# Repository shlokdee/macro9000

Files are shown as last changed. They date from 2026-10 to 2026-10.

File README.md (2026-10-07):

# macro9000
a compact hand wired macropad!
macro9000 is a 9 key rp2040 and qmk based customisable macropad! it can be made without needing to manufacture a pcb! 
it also modularly attaches via trrs cable and uart, with splitkey9000, my hand wired split keyboard... (wip)

### inspiration
every macropad i see has a pcb attached to it. i dont see the need for it to be honest. so i decided to make my own hand wired macropad.

### features:
* 9 customisable keys (with a webtool called via)
* qmk firmware
* fully hand wired, no pcb
* a clean look, with the keys spanning the entirety of the surface

### bom:

|component |use |qty |price |link ||
|---|---|---|---|---|---|
|RP2040-Zero |main microcontroller running qmk |1 |269 |https://robu.in/product/rp2040-zero-for-raspberry-pi-microcontroller-with-soldering/ | |
|1n4148 diode|reduce ghosting |9 |30 |https://robu.in/product/1n4148-onsemi-100v-1v10ma-4ns-200ma-do-35-switching-diodes-rohs/| |
|MX Switches |well, switches |9 (pack of 10) |~250 |TBD | |
|Keycaps |3d Printed keycaps |9 |~100 |probably robu service | |
|Wire |wiring lmao (the wire ive chosen is soo good... tins so easily)|2m (to be safe)|30 |https://robu.in/product/24awg-silicone-braided-wire-red/ | |
|casing |3d printed casing |1 |~300 |probably robu service | |
|shipping |cart values gonna be low so shipping needed lol | |~200 total| | |
|total | | |~1150 | | |
| | | |12 usd | | |
| | | | | | |

### 3d printing
the enclosure and the keycaps are 3d printed. files can be found inside the [3d files](3d_files) folder. I have attached a [3d print arranged file](3d_files/3dpassem.step), you can upload that to a slicer and print!

### schematic and wiring
this is the main schematic to use while wiring..
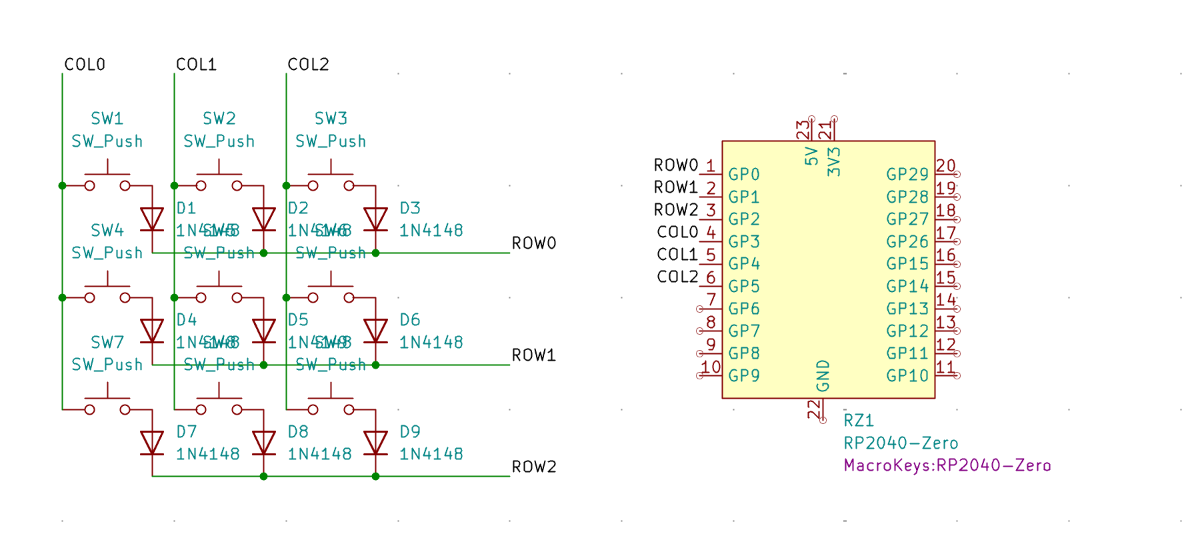
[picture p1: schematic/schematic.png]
schematic


switches should be wired after fitting into the sockets like:
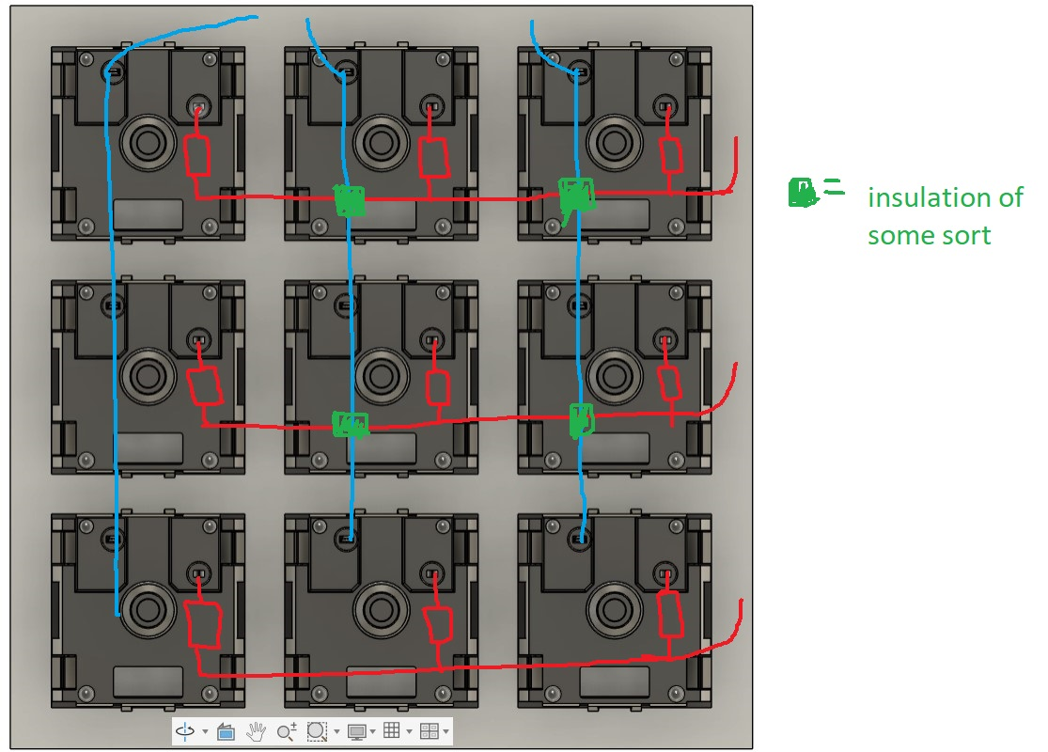
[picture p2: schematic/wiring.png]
wiring


### how to build
* 3d print the case, socket and 9 keycaps. you can use this [file](3d_files/3dpassem.step), directly upload it to the slicer, and print. high quality (0.1mm) is preffered.
* push the mx keys into the slots on the socket. its square, so doesnt matter which way. but for easy wiring, place all the 2 pin sides on the same side (as shown in the wiring diagram)
* solder the diodes, and the wires acc to the wiring diagram, make sure that the leg opposite to the black stripe is connected to the switch leg.
* mount the rp2040 zero in the box, and make the connections acc to the schematic
* mount the trrs female in the box and make its connections too (wip)
* place the socket over the box
* flash the firmware and youre good to go!

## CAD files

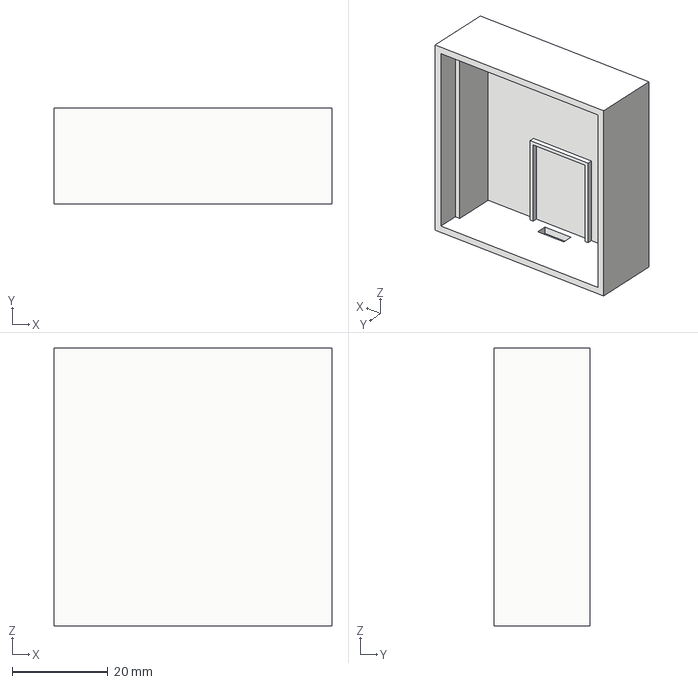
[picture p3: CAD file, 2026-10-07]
3d_files/case.step
58.2 x 20.0 x 58.2 mm

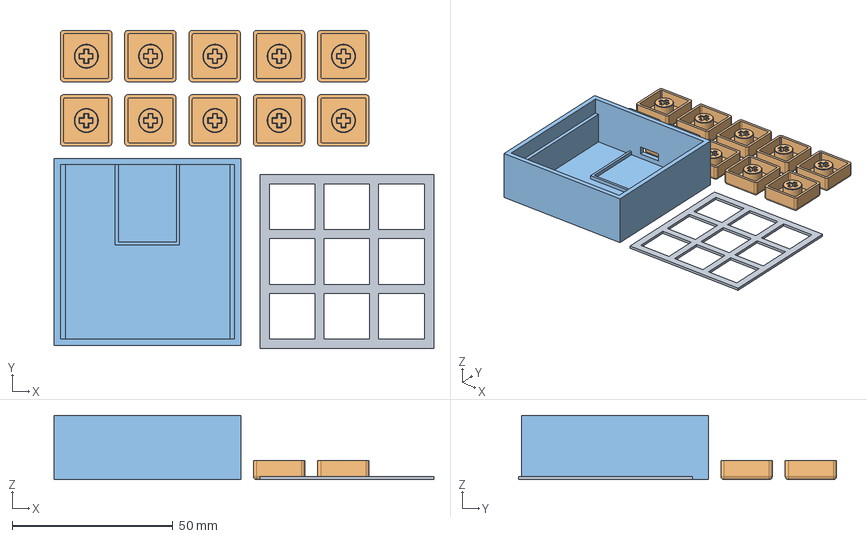
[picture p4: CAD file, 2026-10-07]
3d_files/3dpassem.step
118.2 x 99.0 x 20.0 mm

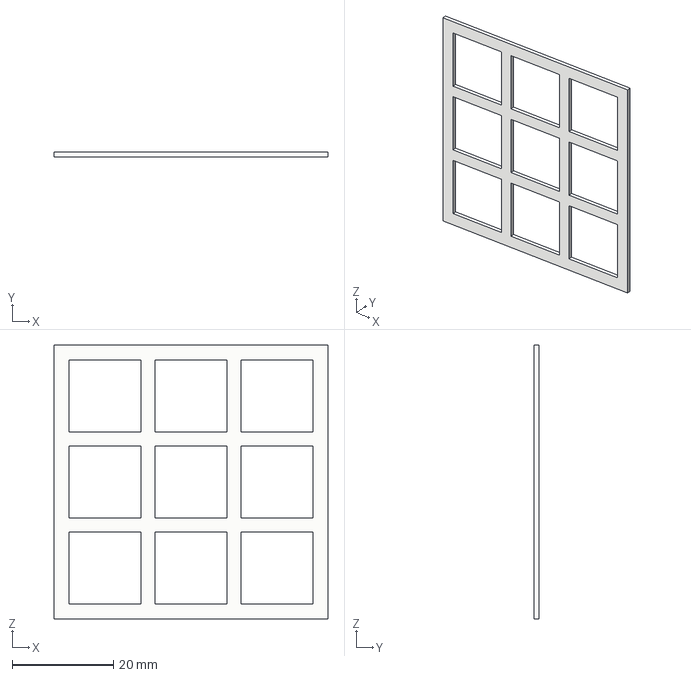
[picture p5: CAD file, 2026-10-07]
3d_files/socket.step
54.2 x 1.00 x 54.2 mm

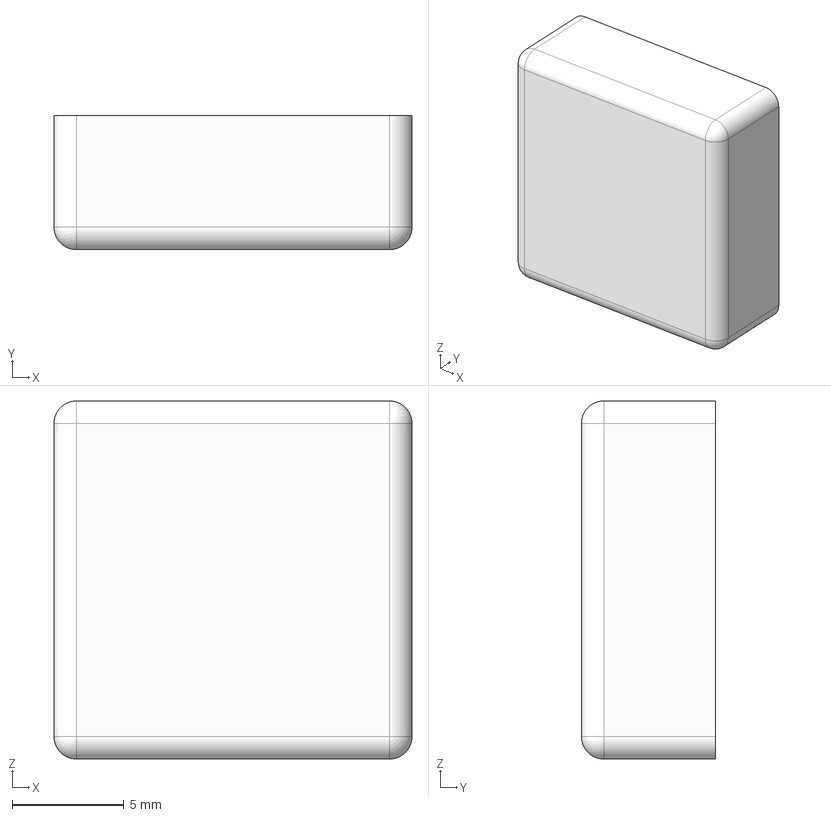
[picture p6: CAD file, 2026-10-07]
3d_files/keycaps.step
16.0 x 6.00 x 16.0 mm

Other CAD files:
3d_files/assembly.f3z

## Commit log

2026-10-05 made a basic bom
    [BOM.csv]
2026-10-05 added diode
    [BOM.csv]
2026-10-07 added the 3d and schematic files
    [3dpassem.step, assembly.f3z, case.step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]
2026-10-07 updated readme (trrs wip)
    [3dpassem.step, assembly.f3z, case.step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]
2026-10-11 updated bom with finalised items and costs
2026-10-11 Update wire
